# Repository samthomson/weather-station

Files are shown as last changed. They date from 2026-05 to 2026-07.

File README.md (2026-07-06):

# Nostr Weather Station

ESP8266 weather station that posts sensor data to Nostr via WebSocket with BIP-340 Schnorr signatures.

**Viewer app:** [github.com/samthomson/weather](https://github.com/samthomson/weather) — sample app for displaying weather data from Nostr events, deployed at [weather.shakespeare.wtf](https://weather.shakespeare.wtf/)

## Hardware

**Supported Boards:**
- NodeMCU v2 (ESP8266)
- ESP32 Dev Board

**Sensors:**
- DHT11 temp/humidity — also works: DHT22
- PMS5003 particulate matter — reads PM1.0, PM2.5, PM10 | also works: PMS7003
- MQ-135/MQ-7 air quality — uncalibrated gas detection 0-1023 | also works: MQ-2, other MQ series
- SSD1306 OLED display (I2C) - optional

### MVP shopping list

Wall-powered reference build for new prototypes: **ESP32**, particulates, temp/humidity/pressure, daylight, rain — **no MQ gas sensor, no OLED**.

| Qty | Part |
|-----|---|
| 1 | ESP32 dev board (same class as `board = esp32dev` in PlatformIO) |
| 1 | BME280 breakout (I2C, 3.3 V) — temperature, humidity, barometric pressure |
| 1 | PMS5003 — PM1.0, PM2.5, PM10 (include a cable if the module does not ship with one) |
| 1 | BH1750 breakout (I2C) — ambient light (lux) |
| 1 | MH-RD rain sensor module (resistive panel, analog out) |
| 1 | USB cable — connector must match the board (**Micro-USB** or **USB-C**) |
| 1 | USB wall charger — **5 V**, **≥ 1 A** (2 A is a comfortable margin for ESP32 + PMS fan) |

Hookup wire or Dupont jumpers between the dev board and breakouts are assumed by your enclosure / assembly.

**MVP firmware:** In `secrets_stationN.h`, enable `ENABLE_BME280`, `ENABLE_BH1750`, `ENABLE_RAIN`, and `ENABLE_PMS` with `PMS_MODEL "PMS5003"`; set `ENABLE_DHT`, `ENABLE_MQ`, and `ENABLE_OLED` to `false`. Use a PlatformIO ESP32 environment that pulls in the BME280 and BH1750 libraries (for example `esp32dev_station3`).

**MVP ESP32 wiring:** PMS5003 serial RX→**GPIO16**, TX→**GPIO17**. BME280 and BH1750 share **I2C** (**GPIO21**=SDA, **GPIO22**=SCL). Rain sensor analog→**GPIO34**.

Stripboard matrix + cable list: **[docs/mvp-assembly-guide.html](docs/mvp-assembly-guide.html)**. Flash & setup: below.

### MVP wire colours

Use **industry-standard** colours for power rails, and **project theme** colours on the nets with the most jumpers. One dupont colour per stripboard row; label GND / 3V3 / 5V on the board edge.

| Net | Dupont colour | Type | Jumpers |
|-----|---|---|---|
| GND | Black | standard | 5 |
| 3.3 V | Orange | theme + standard for 3V3 | 4 |
| 5 V | Red | standard | 2 |
| I²C SDA | Purple | theme | 3 |
| I²C SCL | White | theme | 3 |
| PMS TX → ESP RX | Green | other | 2 |
| ESP TX → PMS RX | Grey | theme | 2 |
| Rain AO | Blue | other | 2 |
| Rain pad → MH-RD | Blue | pad sense | 2 |

**Theme palette** (UI brand + preferred dupont stock): orange, purple, white, grey. Orange does double duty as 3.3 V (common convention). Green and blue are only used on 2-wire nets so all four theme colours land on the busier rows.

### Pin Connections

**ESP8266 (NodeMCU v2):**
- DHT11: D7
- PMS5003: TX→D5, RX→D6
- MQ sensor: A0
- OLED: I2C (D1=SCL, D2=SDA)

**ESP32:**
- DHT11: GPIO4
- PMS5003: TX→GPIO16 (RX2), RX→GPIO17 (TX2)
- MQ sensor: GPIO36 (ADC1_CH0)
- OLED: I2C (GPIO21=SDA, GPIO22=SCL)

**Note:** ESP8266 has one analog pin. ESP32 has many - great for multiple analog sensors!

## Setup

1. Install [PlatformIO](https://platformio.org/).
2. *(Optional)* For brand-new boards you do not need to edit any secrets file — the firmware ships with sensible blank defaults and a per-device captive-portal dashboard handles everything. If you want pre-baked factory defaults (handy if you flash a lot of boards), copy `include/secrets.h.example` to e.g. `include/secrets_station_mvp1.h` and fill it in.
3. Connect the board via USB and flash. For a **brand-new or recycled board**, erase first so NVS starts clean:
   ```bash
   # Erase + flash (new/recycled board — clears all NVS):
   pio run -e esp32dev_mvp3 -t erase && pio run -e esp32dev_mvp3 -t upload

   # Flash only (re-flash same board, keep NVS config):
   pio run -e esp32dev_mvp3 -t upload

   # Monitor serial output:
   pio device monitor -e esp32dev_mvp3
   ```
   Replace `mvp3` with the correct env number. All MVP envs (`esp32dev_mvp1` … `esp32dev_mvp5`) build the **same firmware**; only the first-boot defaults differ (station name `N/5`, etc.). Track which board is which in [`docs/mvp-stations.md`](docs/mvp-stations.md).

   **Do not use `esptool.py` directly** — it is not on PATH and its bundled copy has missing Python dependencies. Always use `pio run -t erase` / `pio run -t upload`.

   Default Nostr relay on first boot: `wss://relay.relaying.earth`.

   **Confirm the right board is connected** before flashing. After boot, serial prints `[wifi] AP SSID: WeatherStation-XXXXXX` every 10 s — verify `XXXXXX` matches the board's label in `docs/mvp-stations.md`.

## Configure from your phone (the dashboard)

The station permanently broadcasts its own open WiFi network for configuration. You don't need a router, an app, or an IP address.

1. Plug the station in.
2. On your phone, join the WiFi named **`WeatherStation-XXXXXX`** (`XXXXXX` is the last 6 hex of the board's MAC). It has no password.
3. The "Sign in to network" sheet pops up automatically with the dashboard. (If not, open a browser to `http://192.168.4.1`.)
4. Set your home WiFi, station name, geohash, etc. Toggle the sensors you actually have wired. Hit Save.
5. The station joins your home WiFi and starts publishing to Nostr.

You can rejoin `WeatherStation-XXXXXX` at any time to change anything — including the home WiFi password if it ever changes. Everything you change persists across power loss (stored in flash / NVS).

Once on the home network you can also reach the dashboard at `http://weather.local` (mDNS).

### What's configurable from the dashboard

- **WiFi (home)** — SSID and password, with a built-in network scan.
- **Station identity** — name, description, geohash (with a "use my GPS" button that pulls from the phone), elevation, power source, connectivity type.
- **Nostr** — relay URL (preset dropdown + custom), private key (auto-generated on first boot; reveal / copy / regenerate / paste-an-existing-one).
- **Sensors** — per-sensor on/off toggles for BME280, BH1750, MH-RD rain, PMS5003/PMS7003. Only sensors you actually have wired need to be on.
- **Advanced** — post interval, restart, factory reset.

## Events Published

### kind:16158 (replaceable) — Station Metadata

Describes the station hardware, power, and sensors:

```json
{
  "tags": [
    ["name", "Weather Station 1"],
    ["g", "w5q6u"],
    ["power", "mains"],
    ["connectivity", "wifi"],
    ["sensor", "temp", "DHT11"],
    ["sensor", "pm25", "PMS5003"]
  ]
}
```

**Power types:** Currently `mains` only. Planned: `solar`, `battery`, `solar_battery`, `usb`  
**Connectivity types:** Currently `wifi` only. Planned: `cellular`, `ethernet`, `lora`, `satellite`

### kind:4223 (regular) — Sensor Readings

Each tag: `[sensor_type, value, model]`

```json
{
  "tags": [
    ["t", "weather"],
    ["a", "16158:<pubkey>:"],
    ["temp", "22.5", "DHT11"],
    ["humidity", "65.2", "DHT11"],
    ["pm25", "12", "PMS5003"],
    ["air_quality", "627", "MQ-135"]
  ]
}
```

**Tag Structure:** Third parameter identifies sensor model for cross-station comparison and multi-sensor setups.

**Units:** temp=°C, humidity=%, pm1/pm25/pm10=µg/m³, air_quality=0-1023 (raw analog)

## Project Structure

```
├── src/main.cpp                   # Sensor reads + Nostr publish
├── src/config_store.cpp           # NVS-backed user config
├── src/web_dashboard.cpp          # Captive-portal dashboard
├── include/config_store.h
├── include/web_dashboard.h
├── include/secrets.h.example      # First-boot factory defaults template
├── include/secrets_station_mvpN.h # Per-board factory defaults
├── platformio.ini
└── README.md
```

## todo

- [ ] automated tests
- [x] web dashboard
- [ ] more modular readings
- [ ] MVP
  - [x] hardware shopping list (see **MVP shopping list** under Hardware)
  - [ ] daylight
  - [ ] rain
  - [ ] air pollution
  - [ ] temperature / humidity
  - [ ] pressure
- [ ] geohash tag for the weather station event per geohash level (https://github.com/nostr-protocol/nips/pull/2163#discussion_r2653978414)
- [ ] faulty sensor/data. omit the sensor reading in the 4223 reading, and mark the sensor as 418 in 16158
- [ ] document that its a string 9https://github.com/nostr-protocol/nips/pull/2163#discussion_r2653971649)
- [ ] nip31 alt tag (for each event?) https://github.com/nostr-protocol/nips/pull/2163#issuecomment-3693704646
- [ ] add `"observed_at": <unix timestamp in seconds>` for each 16158.
- [ ] expand past weather to general environmental data (eg soil acidity, soil moisture, etc). think of a more inclusive name. maybe terrametry (telemetry, but earth scoped)

## Air quality station

A future variant focused on indoor air quality. Goal: factory-calibrated, plug-and-trust — no per-unit calibration or burn-in. All sensors below are I²C (shared GPIO21 SDA / GPIO22 SCL), so they wire in parallel on one ESP32. MQ sensors are deliberately excluded — they need per-unit calibration and only give relative values.

- [ ] PMS5003 — PM1/2.5/10 in µg/m³ (already owned)
- [ ] SCD41 — real CO₂ (NDIR) in ppm, plus temp + humidity
- [ ] SGP41 — VOC + NOx index (relative; good for spotting change/spikes)
- [ ] BME680 (optional) — IAQ gas resistance + temp/humidity/pressure

### Possible future sensors

- [ ] Winsen ZE07-CO / ZE15-CO — carbon monoxide (electrochemical, calibrated; real safety metric). UART, not I²C.
- [ ] Sensirion SFA30 — formaldehyde (HCHO); off-gasses from furniture/flooring. I²C/UART.
- [ ] Radon detector — serious long-term indoor risk, but needs a dedicated (pricier) unit; not an I²C add-on.
- [ ] Sound level (mic) — environmental noise; beyond air quality but useful for an indoor environment station.

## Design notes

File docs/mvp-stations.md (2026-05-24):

# MVP weather stations — local registry

Track which physical ESP32 is which station. Fill in a row after each flash.

**Flash command** (same firmware for every station; env only sets first-boot factory defaults):

```bash
pio run -e esp32dev_mvp1 --target upload   # station 1
pio run -e esp32dev_mvp2 --target upload   # station 2
# … mvp3, mvp4, mvp5
```

**After flash**, read from serial boot log or join the setup WiFi:

- `device_id` — last 6 hex of MAC (also the `device_id` Nostr tag)
- Setup AP — `WeatherStation-XXXXXX` (same 6 hex suffix)
- Full MAC — printed by esptool during upload

**Reassigning a board** (e.g. old prototype #3 → production #1): flashing alone does **not** wipe dashboard config. Either use **Factory reset** on the dashboard, or update name/relay/WiFi manually.

**Default relay** (first boot only): `wss://relay.relaying.earth`

---

| # | PlatformIO env | device_id | Setup AP (SSID) | Full MAC | Flashed | Notes |
|---|---|---|---|---|---|---|
| 1 | esp32dev_mvp1 | B865E4 | WeatherStation-B865E4  | e4:65:b8:1b:43:08  | 2026-05-24 | OLD firmware (wrong MAC suffix); will become 1B4308 after reflash |
| 2 | esp32dev_mvp2 | B3A3A0 | WeatherStation-B3A3A0  | a0:a3:b3:2f:95:d8  | 2026-05-24 | OLD firmware (wrong MAC suffix); will become 2F95D8 after reflash |
| 3 | esp32dev_mvp3 | 19D3B8 | WeatherStation-19D3B8  | e4:65:b8:19:d3:b8  | 2026-05-24 | Fixed firmware flashed |
| 4 | esp32dev_mvp4 | 3141C4 | WeatherStation-3141C4  | | 2026-05-24 | |
| 5 | esp32dev_mvp5 | 0BF6BC | WeatherStation-0BF6BC  | | 2026-05-24 | |

---

## Optional (keep private)

| # | Nostr pubkey | Home WiFi SSID | Location / geohash |
|---|---|---|---|
| 1 | | | |
| 2 | | | |
| 3 | | | |
| 4 | | | |
| 5 | | | |

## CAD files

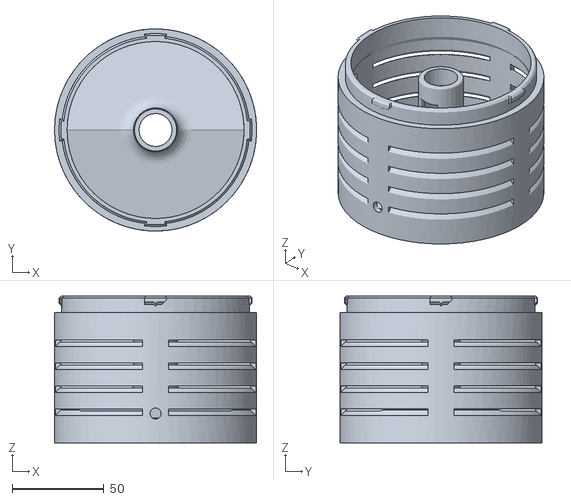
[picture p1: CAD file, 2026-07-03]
3d_files/2c_tier_louvred.stl
109.9 x 110.0 x 79.9

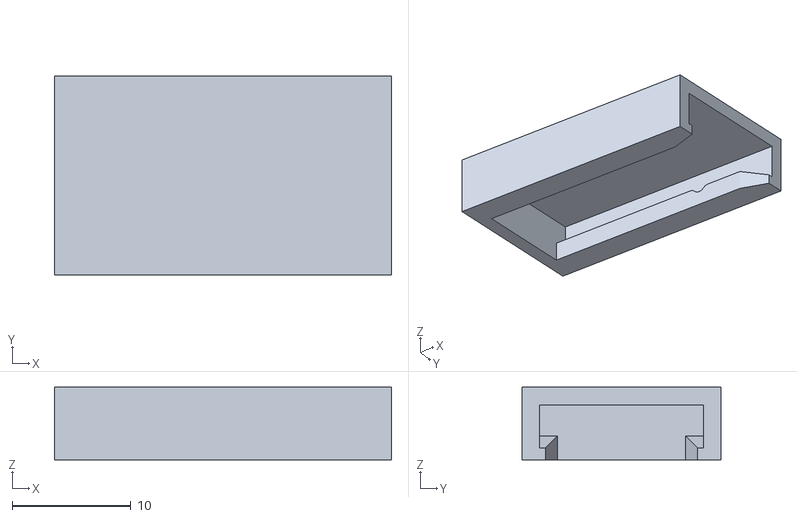
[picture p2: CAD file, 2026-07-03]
3d_files/3b2_rain_sensor_cover.stl
28.4 x 16.8 x 6.10

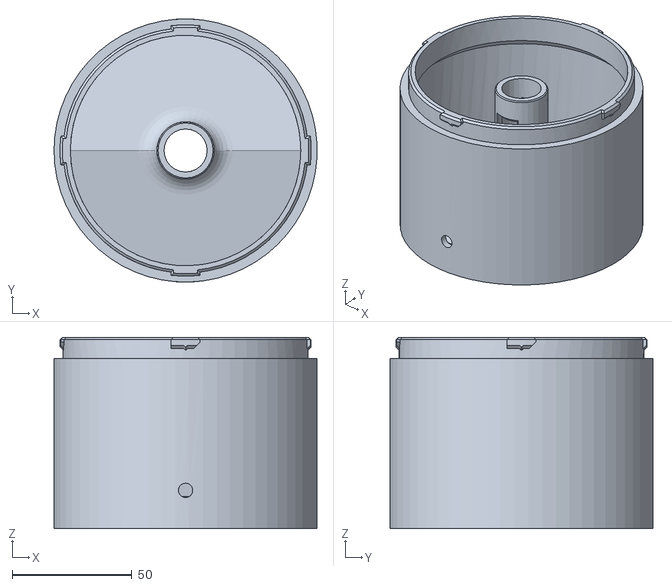
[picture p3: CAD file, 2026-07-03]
3d_files/2b_tier_solid.stl
109.9 x 110.0 x 79.9

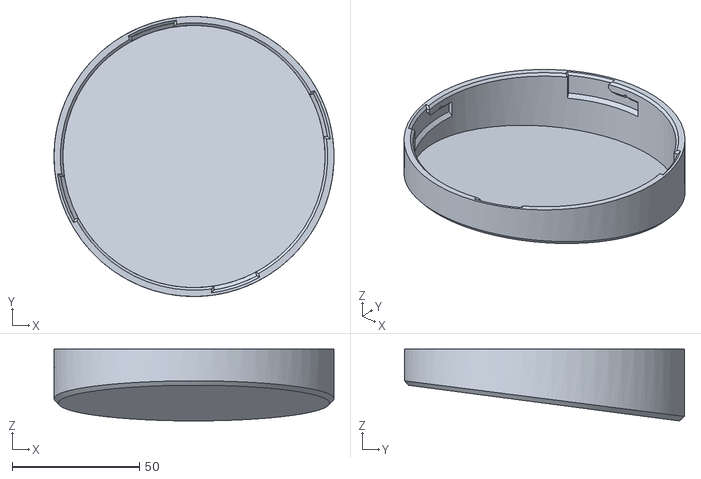
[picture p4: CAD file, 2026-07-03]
3d_files/3a_plain roof.stl
110.0 x 110.0 x 28.2

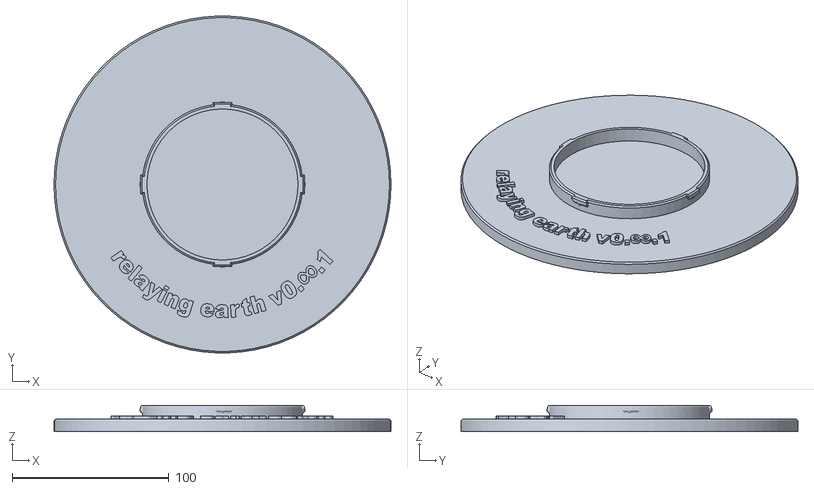
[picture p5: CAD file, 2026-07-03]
3d_files/1_base_with_text.stl
215.0 x 214.8 x 16.9

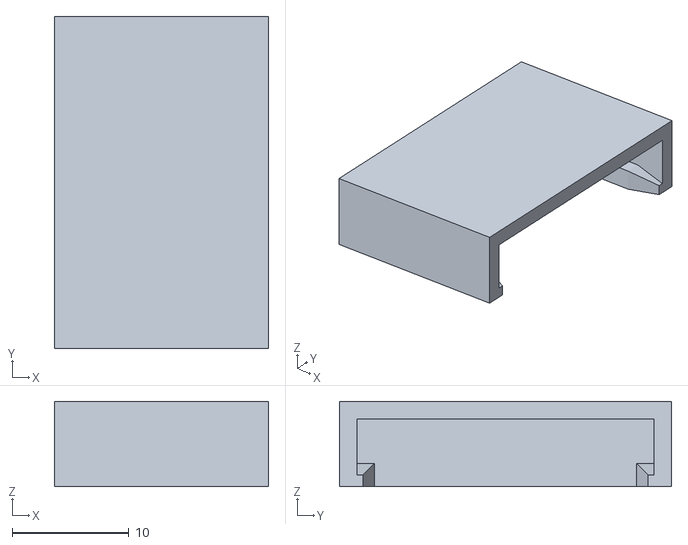
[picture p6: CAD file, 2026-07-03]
3d_files/3b3_light_sensor_cover.stl
18.4 x 28.4 x 7.30

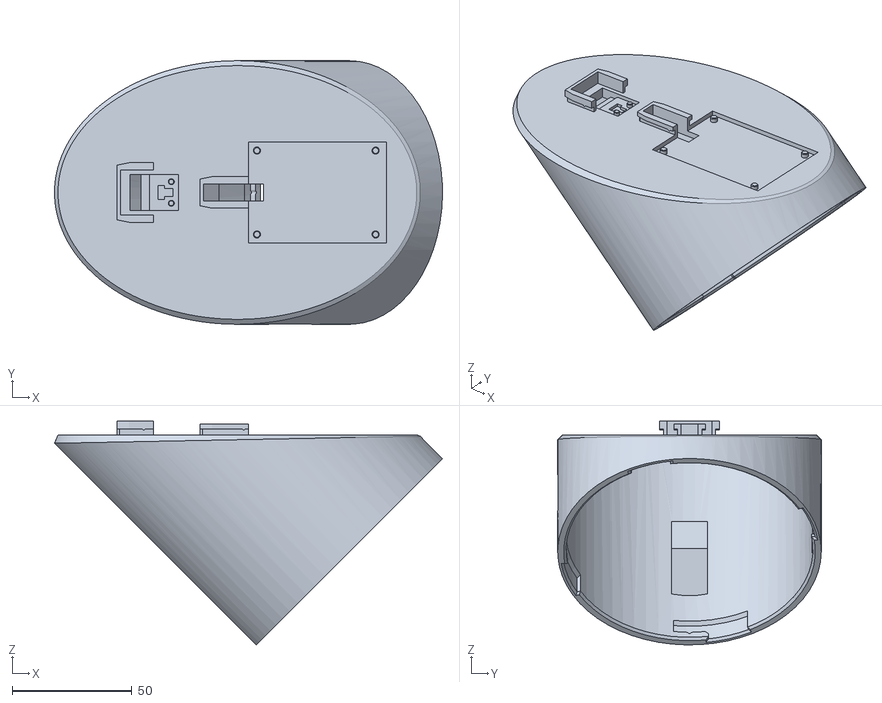
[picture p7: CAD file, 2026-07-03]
3d_files/3b_roof_with_sensors.stl
161.9 x 110.0 x 93.4

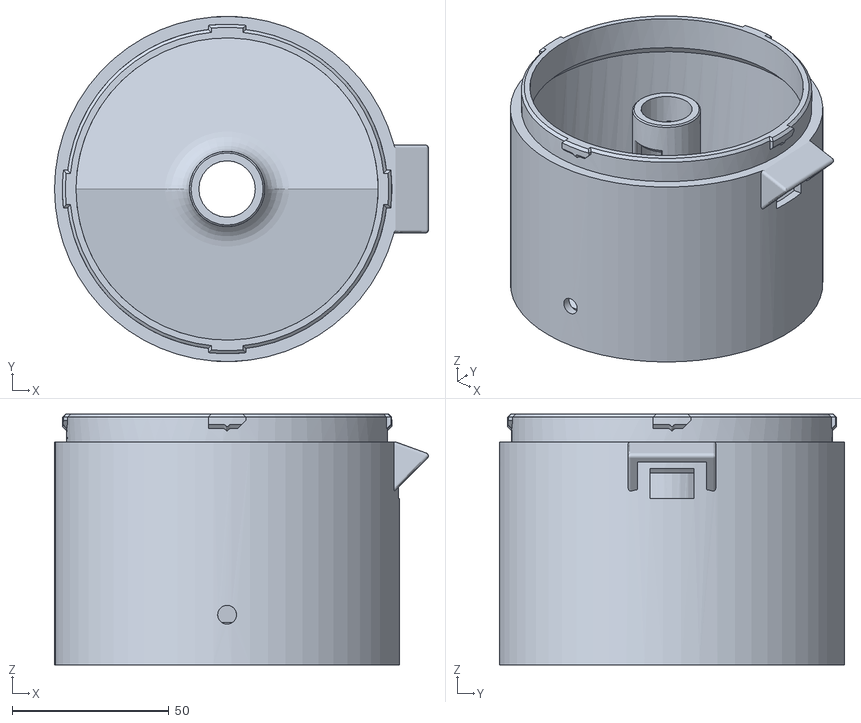
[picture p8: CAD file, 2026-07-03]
3d_files/2a_tier_esp32.stl
119.2 x 110.0 x 79.9

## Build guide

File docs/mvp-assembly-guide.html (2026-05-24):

# Weather Station — Stripboard Build

30-pin ESP32 · 6×9 cm stripboard · rows 1–8 from top

## Stripboard matrix

One row = one net. Solder each pin into any hole on that row. Male dupont leg through hole, bend on copper side. ESP32 off-board (F on ESP, M soldered).

Row | Net | ESP32 DevKitUSB at top · 30-pin | BME280I²C + 3V3 rail | BH1750I²C + 3V3 rail | PMS50035V UART | MH-RD rain3V3 + AO
1 | GND | BlackGND (left · pin 2) | BlackGND | BlackGND | BlackGND | BlackGND
2 | 3V3 | Orange3V3 | OrangeVCC | OrangeVCC | — | OrangeVCC
3 | I²C SDA | PurpleD21 | PurpleSDA | PurpleSDA | — | —
4 | I²C SCL | WhiteD22 | WhiteSCL | WhiteSCL | — | —
5 | UART PMS → ESP | GreenRX2 | — | — | GreenTXD | —
6 | UART ESP → PMS | GreyTX2 | — | — | GreyRXD | —
7 | 5V | RedVIN | — | — | RedVCC | —
8 | Rain analog | BlueD34 | — | — | — | BlueAO

## Cables

Male end soldered to perfboard on stubs. Column plugs stub ↔ tail at each tier. Wire bars are to scale (10 px wide = 1 cm).

ESP32
15 cm · F–M · perfboard stubs
Black Orange Purple White Green Grey Red Blue
BME280
15 cm · F–M · perfboard stubs
Black Orange Purple White
30 cm · M–M · column (stack connectors)
Black Orange Purple White
10 cm · F–M · sensor tails
Black Orange Purple White
BH1750
15 cm · F–M · perfboard stubs
Black Orange Purple White
30 cm · M–M · column (stack connectors)
Black Orange Purple White
10 cm · F–M · sensor tails
Black Orange Purple White
PMS5003
15 cm · F–M · perfboard stubs
Black Green Grey Red
30 cm · M–M · column (stack connectors)
Black Green Grey Red
10 cm · F–M · sensor tails
Black Green Grey Red
MH-RD board
15 cm · F–M · perfboard stubs
Black Orange Blue
30 cm · M–M · column (stack connectors)
Black Orange Blue
Rain pad → MH-RD
10 cm · F–F · component (rain pad)
Blue Blue

### Shopping list

ESP32
15 cm · F–M · perfboard stubs
Qty | Wire
1 | Black
1 | Orange
1 | Purple
1 | White
1 | Green
1 | Grey
1 | Red
1 | Blue
BME280
15 cm · F–M · perfboard stubs
Qty | Wire
1 | Black
1 | Orange
1 | Purple
1 | White
30 cm · M–M · column (stack connectors)
1 | Black
1 | Orange
1 | Purple
1 | White
10 cm · F–M · sensor tails
1 | Black
1 | Orange
1 | Purple
1 | White
BH1750
15 cm · F–M · perfboard stubs
Qty | Wire
1 | Black
1 | Orange
1 | Purple
1 | White
30 cm · M–M · column (stack connectors)
1 | Black
1 | Orange
1 | Purple
1 | White
10 cm · F–M · sensor tails
1 | Black
1 | Orange
1 | Purple
1 | White
PMS5003
15 cm · F–M · perfboard stubs
Qty | Wire
1 | Black
1 | Green
1 | Grey
1 | Red
30 cm · M–M · column (stack connectors)
1 | Black
1 | Green
1 | Grey
1 | Red
10 cm · F–M · sensor tails
1 | Black
1 | Green
1 | Grey
1 | Red
MH-RD board
15 cm · F–M · perfboard stubs
Qty | Wire
1 | Black
1 | Orange
1 | Blue
30 cm · M–M · column (stack connectors)
1 | Black
1 | Orange
1 | Blue
Rain pad → MH-RD
10 cm · F–F · component (rain pad)
Qty | Wire
2 | Blue
52 wires total

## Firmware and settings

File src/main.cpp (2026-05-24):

#include <Arduino.h>
#include <math.h>

// Include station-specific secrets FIRST (defines sensor flags)
#ifndef SECRETS_FILE
  #error "SECRETS_FILE must be defined! Use -DSECRETS_FILE=\"secrets_stationX.h\" in platformio.ini"
#endif
#include SECRETS_FILE

// Board-specific includes
#ifdef ESP32
  #include <WiFi.h>
  #include <WiFiClientSecure.h>
  #include "soc/soc.h"
  #include "soc/rtc_cntl_reg.h"
#else
  #include <ESP8266WiFi.h>
  #include <WiFiClientSecure.h>
  #include <SoftwareSerial.h>
#endif

#include <time.h>
#include <ArduinoJson.h>
#if ENABLE_DHT
  #include "DHT.h"
#endif
#include <Wire.h>
#if ENABLE_BME280
  #include <Adafruit_BME280.h>
  #include <Adafruit_BMP280.h>
#endif
#if ENABLE_BH1750
  #include <BH1750.h>
#endif
#if ENABLE_SPS30
  #include <SensirionI2cSps30.h>
#endif
#if ENABLE_SDS011
  #include <SdsDustSensor.h>
#endif
#include <Adafruit_GFX.h>
#include <Adafruit_SSD1306.h>
#include <WebSocketsClient.h>

#include "config_store.h"
#include "web_dashboard.h"

#ifdef ESP32
  #include <mbedtls/sha256.h>
  #include "uECC.h"
#else
  #include <bearssl/bearssl_hash.h>
  #include "uECC.h"
#endif

// secp256k1 curve order n
static const uint8_t SECP256K1_ORDER[32] = {
  0xFF, 0xFF, 0xFF, 0xFF, 0xFF, 0xFF, 0xFF, 0xFF,
  0xFF, 0xFF, 0xFF, 0xFF, 0xFF, 0xFF, 0xFF, 0xFE,
  0xBA, 0xAE, 0xDC, 0xE6, 0xAF, 0x48, 0xA0, 0x3B,
  0xBF, 0xD2, 0x5E, 0x8C, 0xD0, 0x36, 0x41, 0x41
};

// Pre-computed tag hashes for BIP-340
static const uint8_t TAG_CHALLENGE[32] = {
  0x7b, 0xb5, 0x2d, 0x7a, 0x9f, 0xef, 0x58, 0x32,
  0x3e, 0xb1, 0xbf, 0x7a, 0x40, 0x7d, 0xb3, 0x82,
  0xd2, 0xf3, 0xf2, 0xd8, 0x1b, 0xb1, 0x22, 0x4f,
  0x49, 0xfe, 0x51, 0x8f, 0x6d, 0x48, 0xd3, 0x7c
};
static const uint8_t TAG_NONCE[32] = {
  0x07, 0x49, 0x77, 0x34, 0xa7, 0x9b, 0xcb, 0x35,
  0x5b, 0x9b, 0x8c, 0x7d, 0x03, 0x4f, 0x12, 0x1c,
  0xf4, 0x34, 0xd7, 0x3a, 0xf6, 0x39, 0x7b, 0x96,
  0xb8, 0x0a, 0xab, 0x80, 0x51, 0x85, 0x45, 0x69
};
static const uint8_t TAG_AUX[32] = {
  0xf1, 0xef, 0x4e, 0x5e, 0xc0, 0x63, 0xca, 0xda,
  0xf7, 0xef, 0xf4, 0xb9, 0x8e, 0x3b, 0x67, 0xc8,
  0xa7, 0x90, 0xae, 0xfe, 0x0f, 0x05, 0xfc, 0x7a,
  0x5f, 0x21, 0xa9, 0x93, 0x01, 0x6c, 0x3a, 0xba
};

// All user-settable values come from config_store::current(); the compile-time
// #defines in SECRETS_FILE are only consulted on first boot to seed NVS.
// Default values for things that aren't user-settable from the dashboard yet:
const uint16_t NOSTR_DEFAULT_TLS_PORT = 443;
const uint16_t NOSTR_DEFAULT_WS_PORT  = 80;

// Parsed relay URL kept in sync with config_store::current().nostr_relay.
struct RelayURL { String host; uint16_t port; String path; bool ssl; };
static RelayURL currentRelay;

// Nostr tag names (standardized)
const char* TAG_TEMP = "temp";
const char* TAG_HUMIDITY = "humidity";
const char* TAG_PM1 = "pm1";
const char* TAG_PM25 = "pm25";
const char* TAG_PM10 = "pm10";
const char* TAG_AIR_QUALITY = "air_quality";
const char* TAG_HASHTAG = "t";
const char* HASHTAG_WEATHER = "weather";

// Sensor models
const char* MODEL_DHT11 = "DHT11";
const char* MODEL_BME280 = "BME280";
const char* MODEL_BMP280 = "BMP280";
const char* MODEL_PMS5003 = "PMS5003";
const char* MODEL_PMS7003 = "PMS7003";
const char* MODEL_SPS30 = "SPS30";
const char* MODEL_SDS011 = "SDS011";
const char* MODEL_MQ135 = "MQ-135";
const char* MODEL_BH1750 = "BH1750";
const char* MODEL_MHRD = "MH-RD";

// Nostr tag names for additional sensors
const char* TAG_PRESSURE = "pressure";
const char* TAG_LIGHT = "light";
const char* TAG_RAIN = "rain";

// Sensor types available on this station (for metadata)
struct SensorInfo {
  const char* type;
  const char* model;
};

// Build sensor list modularly - each enabled sensor adds its readings
// Validate that required models are defined if sensors are enabled
#if ENABLE_PMS && !defined(PMS_MODEL)
  #error "PMS_MODEL must be defined in secrets file when ENABLE_PMS is true"
#endif

const SensorInfo sensors[] = {
  #if ENABLE_DHT
    {TAG_TEMP, MODEL_DHT11},
    {TAG_HUMIDITY, MODEL_DHT11},
  #endif
  #if ENABLE_BME280
    {TAG_TEMP, MODEL_BME280},
    {TAG_HUMIDITY, MODEL_BME280},  // Only for BME280, not BMP280
    {TAG_PRESSURE, MODEL_BME280},
  #endif
  #if ENABLE_BMP280
    {TAG_TEMP, MODEL_BMP280},
    {TAG_PRESSURE, MODEL_BMP280},
  #endif
  #if ENABLE_PMS
    {TAG_PM1, PMS_MODEL},
    {TAG_PM25, PMS_MODEL},
    {TAG_PM10, PMS_MODEL},
  #endif
  #if ENABLE_SPS30
    {TAG_PM1, MODEL_SPS30},
    {TAG_PM25, MODEL_SPS30},
    {TAG_PM10, MODEL_SPS30},
  #endif
  #if ENABLE_SDS011
    {TAG_PM25, MODEL_SDS011},
    {TAG_PM10, MODEL_SDS011},
  #endif
  #if ENABLE_MQ
    {TAG_AIR_QUALITY, MODEL_MQ135},
  #endif
};

const int sensorCount = sizeof(sensors) / sizeof(sensors[0]);

// PM sensor serial port - board-specific (PMS5003/PMS7003 and SDS011)
#ifdef ESP32
  HardwareSerial pmsSerial(2);  // ESP32 UART2
  #define PMS_SERIAL pmsSerial
#else
  SoftwareSerial mySerial(D5, D6);  // ESP8266
  #define PMS_SERIAL mySerial
#endif

unsigned int pm1 = 0, pm2_5 = 0, pm10 = 0;
bool pmDataReceived = false;  // set on first valid PM frame; omit PM reading tags until then (NIP)

#if ENABLE_SPS30
  SensirionI2cSps30 sps30;
  bool sps30DataReceived = false;
#endif
#if ENABLE_SDS011
  SdsDustSensor sds011(PMS_SERIAL);  // Uses same UART2 on ESP32 (RX=16, TX=17)
  bool sds011DataReceived = false;
#endif

// DHT sensor pin - board-specific
#if ENABLE_DHT
  #define DHTTYPE DHT11
  #ifdef ESP32
    #define DHT_PIN 4  // GPIO4 on ESP32
  #else
    #define DHT_PIN D7  // D7 on ESP8266
  #endif
  DHT dht(DHT_PIN, DHTTYPE);
#endif

// BME280/BMP280 sensor (I2C)
#if ENABLE_BME280
  Adafruit_BME280 bme;
  Adafruit_BMP280 bmp;
  bool bmeAvailable = false;
  bool bmpAvailable = false;  // BMP280 = no humidity, just temp+pressure
  bool bmeHasReading = false;
  bool bmpHasReading = false;
#endif

// BH1750 light sensor (I2C)
#if ENABLE_BH1750
  BH1750 lightMeter;
  bool bh1750Available = false;
#endif

// Rain sensor pin - board-specific
#ifdef ESP32
  #define RAIN_PIN 34  // GPIO34 (ADC1_CH6) on ESP32
#else
  #define RAIN_PIN A0  // A0 on ESP8266 (shared with MQ if both enabled)
#endif

float t = 0, h = 0, p = 0;  // temperature, humidity, pressure
float lux = NAN;            // BH1750 lux; NAN until first valid read
unsigned int rainValue = 0; // rain sensor (0-4095 on ESP32, 0-1023 on ESP8266)

// MQ sensor analog pin - board-specific
#ifdef ESP32
  #define MQ_PIN 36  // GPIO36 (ADC1_CH0) on ESP32
#else
  #define MQ_PIN A0  // A0 on ESP8266
#endif
unsigned int airQuality = 0;
#define SCREEN_WIDTH 128
#define SCREEN_HEIGHT 64
Adafruit_SSD1306 display(SCREEN_WIDTH, SCREEN_HEIGHT, &Wire, -1);
WebSocketsClient webSocket;
bool wsConnected = false;
bool displayAvailable = false;
String nostrPubkey = "";
uint8_t privKeyBytes[32];
uint8_t pubKeyBytes[32];
// millis() of last successful publish; surfaced on the dashboard.
unsigned long lastPublishMs = 0;

// Forward declarations
void connectWiFi();
void setupNostrRelay();
static RelayURL parseRelayUrl(const String& url);
static void applyConfigChanges(bool wifiChanged, bool relayChanged, bool keyChanged, bool sensorsChanged, bool intervalChanged);
static void publishDashboardStatus();
static void initRuntimeSensors();
static WxConfig buildFactoryDefaults();
// 6-char uppercase hex suffix of the eFuse MAC. Stable per physical board,
// burned at factory, identical to the AP SSID suffix.
static String getDeviceId();
void webSocketEvent(WStype_t type, uint8_t* payload, size_t length);
void pmReadData();
#if ENABLE_SPS30
void sps30ReadData();
#endif
#if ENABLE_SDS011
void sds011ReadData();
#endif
void dhtData();
#if ENABLE_BME280
void bmeData();
#endif
#if ENABLE_BH1750
void lightData();
#endif
#if ENABLE_RAIN
void rainData();
// GPIO34 has no internal pull, so a "not connected" pin reads random noise
// across the full ADC range. We treat the sensor as present only after we've
// seen several consecutive stable, high (dry) readings -- a signature a
// floating pin never holds. Once latched, every subsequent reading is treated
// as real weather data regardless of value.
static unsigned rainSpread = 999;
static unsigned rainSampleCount = 0;
static unsigned rainDryStreak = 0;
static bool rainEverConnected = false;

static bool rainValid() { return rainEverConnected; }

static void rainUpdateConnectedLatch(unsigned avg, unsigned spread) {
  if (rainEverConnected) return;
  if (spread <= 80 && avg >= 1800) rainDryStreak++;
  else rainDryStreak = 0;
  if (rainDryStreak >= 5) rainEverConnected = true;
}
#endif
void mqReadData();
void displayOled();
void derivePubkey();
String bytesToHex(uint8_t* bytes, int len);
void hexToBytes(const char* hex, uint8_t* bytes, int len);
void sha256Raw(const uint8_t* data, size_t len, uint8_t* out);
void taggedHash(const uint8_t* tag, const uint8_t* data, size_t len, uint8_t* out);
bool schnorrSign(const uint8_t* privkey, const uint8_t* msg, uint8_t* sig);
String createAndSignNostrEvent(float temp, float humidity, unsigned int pm1_val, unsigned int pm25_val, unsigned int pm10_val, unsigned int aq_val);
String createMetadataEvent();
void sendMetadataEvent();

// --- Tag builders (Nostr reading + metadata tags) ---
static void appendReadingTag(String& dest, const char* type, const char* model, float value) {
  dest += ",[\""; dest += type; dest += "\",\""; dest += String(value, 1); dest += "\",\""; dest += model; dest += "\"]";
}
static void appendReadingTag(String& dest, const char* type, const char* model, unsigned int value) {
  dest += ",[\""; dest += type; dest += "\",\""; dest += String(value); dest += "\",\""; dest += model; dest += "\"]";
}
static void appendSensorTag(String& dest, const char* type, const char* model) {
  dest += ",[\"sensor\",\""; dest += type; dest += "\",\""; dest += model; dest += "\"]";
}
static void appendSensorStatusTag(String& dest, const char* type, const char* model, bool ok) {
  dest += ",[\"sensor_status\",\""; dest += type; dest += "\",\""; dest += model; dest += "\",\""; dest += (ok ? "ok" : "418"); dest += "\"]";
}
// One (type, model) → always add sensor tag + sensor_status(ok). Use for DHT, BH1750, Rain, PMS, MQ.
static void appendSensorAndStatus(String& dest, const char* type, const char* model, bool ok) {
  appendSensorTag(dest, type, model);
  appendSensorStatusTag(dest, type, model, ok);
}

// --- Per-sensor validation (NIP: omit reading / status 418 when invalid) ---
// Each sensor type has one validator. Rain/MQ have no fault detection, so we always pass true for them.
#if ENABLE_DHT
static bool dhtValid() { return !isnan(t) && !isnan(h); }
#endif
#if ENABLE_BME280
static bool enviroReadingOkForNostr() { return (bmeAvailable && bmeHasReading) || (bmpAvailable && bmpHasReading); }

// BME280 sensor range (datasheet); values outside are almost always corrupt I2C frames.
static bool bmeEnviroPlausible(float tempC, float humPct, float pressHpa) {
  if (isnan((double)tempC) || isnan((double)humPct) || isnan((double)pressHpa)) return false;
  if (tempC < -40.0f || tempC > 85.0f) return false;
  if (humPct < 0.0f || humPct > 100.0f) return false;
  if (pressHpa < 260.0f || pressHpa > 1100.0f) return false;
  return true;
}
#endif
#if ENABLE_PMS
static bool pmsValid() { return pmDataReceived; }  // set on first valid frame; omit PM tags until then (NIP)
#endif
#if ENABLE_SPS30
static bool sps30Valid() { return sps30DataReceived; }
#endif
#if ENABLE_SDS011
static bool sds011Valid() { return sds011DataReceived; }
#endif
#if ENABLE_BH1750
// claws/BH1750 returns negative values on I2C read failure — do not relay as lux.
static bool bh1750Valid() {
  return bh1750Available && !isnan((double)lux) && lux >= 0.0f;
}
#endif

// BME280 (temp+humidity+pressure) vs BMP280 (temp+pressure only) — one helper, two model names
#if ENABLE_BME280
static void appendPressureSensorReadingTags(String& dest, const char* model, bool includeHumidity) {
  appendReadingTag(dest, TAG_TEMP, model, t);
  if (includeHumidity) appendReadingTag(dest, TAG_HUMIDITY, model, h);
  appendReadingTag(dest, TAG_PRESSURE, model, p);
}
static void appendPressureSensorMetadataTags(String& dest, const char* model, bool includeHumidity, bool ok) {
  if (ok) {
    appendSensorTag(dest, TAG_TEMP, model);
    if (includeHumidity) appendSensorTag(dest, TAG_HUMIDITY, model);
    appendSensorTag(dest, TAG_PRESSURE, model);
  }
  appendSensorStatusTag(dest, TAG_TEMP, model, ok);
  if (includeHumidity) appendSensorStatusTag(dest, TAG_HUMIDITY, model, ok);
  appendSensorStatusTag(dest, TAG_PRESSURE, model, ok);
}
#endif
#if ENABLE_DHT
static void appendDhtReadingTags(String& dest) {
  if (!dhtValid()) return;
  appendReadingTag(dest, TAG_TEMP, MODEL_DHT11, t);
  appendReadingTag(dest, TAG_HUMIDITY, MODEL_DHT11, h);
}
#endif
// Shared helper: append pm1, pm25, pm10 with given model (used by PMS and SPS30)
static void appendPmReadingTagsWithModel(String& dest, const char* model, unsigned int v1, unsigned int v25, unsigned int v10) {
  appendReadingTag(dest, TAG_PM1, model, v1);
  appendReadingTag(dest, TAG_PM25, model, v25);
  appendReadingTag(dest, TAG_PM10, model, v10);
}
#if ENABLE_PMS
static void appendPmReadingTags(String& dest) {
  if (!pmsValid()) return;
  appendPmReadingTagsWithModel(dest, PMS_MODEL, pm1, pm2_5, pm10);
}
#endif
#if ENABLE_SPS30
static void appendSps30ReadingTags(String& dest) {
  if (!sps30Valid()) return;
  appendPmReadingTagsWithModel(dest, MODEL_SPS30, pm1, pm2_5, pm10);
}
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
void loop() {
  // Always service the dashboard + DNS captive portal first so the UI stays
  // responsive even when STA / WebSocket are flapping.
  web_dashboard::handle();
  webSocket.loop();

  WxConfig& cfg = config_store::current();

  // Best-effort background STA reconnect if user has WiFi creds but we are
  // currently disconnected (e.g. credentials were just changed).
  static unsigned long lastStaRetry = 0;
  if (cfg.wifi_ssid.length() > 0 && WiFi.status() != WL_CONNECTED && millis() - lastStaRetry > 15000) {
    Serial.println("[wifi] reconnect attempt");
    WiFi.begin(cfg.wifi_ssid.c_str(), cfg.wifi_pass.c_str());
    lastStaRetry = millis();
  }

  static unsigned long lastSensor = 0, lastPost = 0, lastStatus = 0, lastWifiLog = 0;
  unsigned long now = millis();

  if (now - lastWifiLog > 10000) {
    lastWifiLog = now;
    Serial.printf("[wifi] AP SSID: %s  AP IP: %s  STA: %s\n",
      web_dashboard::apSsid().c_str(),
      web_dashboard::apIp().c_str(),
      WiFi.status() == WL_CONNECTED ? WiFi.localIP().toString().c_str() : "disconnected");
  }

  if (now - lastSensor > 2000) {
    #if ENABLE_PMS
      if (cfg.en_pms) pmReadData();
    #endif
    #if ENABLE_SPS30
      sps30ReadData();
    #endif
    #if ENABLE_SDS011
      sds011ReadData();
    #endif
    #if ENABLE_DHT
      dhtData();
    #endif
    #if ENABLE_BME280
      if (cfg.en_bme280) bmeData();
    #endif
    #if ENABLE_BH1750
      if (cfg.en_bh1750) lightData();
    #endif
    #if ENABLE_RAIN
      if (cfg.en_rain) rainData();
    #endif
    #if ENABLE_MQ
      mqReadData();
    #endif
    #if ENABLE_OLED
      displayOled();
    #endif
    lastSensor = now;
  }

  if (now - lastStatus > 1000) {
    publishDashboardStatus();
    lastStatus = now;
  }

  uint32_t postIntervalMs = cfg.post_interval_ms > 10000 ? cfg.post_interval_ms : 60000;
  if (now - lastPost > postIntervalMs) {
    // Do we have any valid reading to publish? Each validator already returns
    // false when the sensor is runtime-disabled (because nothing wrote to the
    // backing globals), so we don't re-check cfg.en_* here.
    bool hasData = false;
    #if ENABLE_DHT
      hasData = hasData || (t > 0);
    #endif
    #if ENABLE_BME280
      hasData = hasData || enviroReadingOkForNostr();
    #endif
    #if ENABLE_BH1750
      hasData = hasData || bh1750Valid();
    #endif
    #if ENABLE_RAIN
      hasData = hasData || rainValid();
    #endif
    #if ENABLE_PMS
      hasData = hasData || (pm2_5 > 0);
    #endif
    #if ENABLE_SPS30
      hasData = hasData || sps30DataReceived;
    #endif
    #if ENABLE_SDS011
      hasData = hasData || sds011DataReceived;
    #endif

    if (wsConnected && (hasData || !ENABLE_DHT)) {
      String event = createAndSignNostrEvent(t, h, pm1, pm2_5, pm10, airQuality);
      if (event.length() > 0) {
        Serial.println("Sending reading event...");
        String msg = "[\"EVENT\"," + event + "]";
        webSocket.sendTXT(msg);
        lastPublishMs = millis();
      }
      sendMetadataEvent();
    }
    lastPost = now;
  }
  delay(2);
}

void connectWiFi() {
  WxConfig& cfg = config_store::current();
  if (cfg.wifi_ssid.length() == 0) {
    Serial.println("[wifi] No SSID set; staying in AP-only mode for now");
    return;
  }
  // AP mode is already running (see web_dashboard::begin); WIFI_AP_STA was set
  // there. Just start the STA connection.
  WiFi.begin(cfg.wifi_ssid.c_str(), cfg.wifi_pass.c_str());
  Serial.print("WiFi");
  unsigned long start = millis();
  while (WiFi.status() != WL_CONNECTED && millis() - start < 15000) {
    delay(500);
    Serial.print(".");
  }
  if (WiFi.status() == WL_CONNECTED) {
    Serial.print(" OK ");
    Serial.println(WiFi.localIP());
  } else {
    Serial.println(" timeout (continuing; STA will retry in background)");
  }
}

static RelayURL parseRelayUrl(const String& url) {
  RelayURL r{ "", NOSTR_DEFAULT_TLS_PORT, "/", true };
  if (url.length() == 0) return r;
  String u = url;
  if (u.startsWith("wss://"))      { r.ssl = true;  r.port = NOSTR_DEFAULT_TLS_PORT; u = u.substring(6); }
  else if (u.startsWith("ws://"))  { r.ssl = false; r.port = NOSTR_DEFAULT_WS_PORT;  u = u.substring(5); }
  // bare "host[:port][/path]" defaults to wss://
  int slash = u.indexOf('/');
  String hostport = slash >= 0 ? u.substring(0, slash) : u;
  r.path = slash >= 0 ? u.substring(slash) : "/";
  int colon = hostport.indexOf(':');
  if (colon >= 0) {
    r.host = hostport.substring(0, colon);
    r.port = (uint16_t)hostport.substring(colon + 1).toInt();
  } else {
    r.host = hostport;
  }
  return r;
}

void setupNostrRelay() {
  WxConfig& cfg = config_store::current();
  currentRelay = parseRelayUrl(cfg.nostr_relay);
  if (currentRelay.host.length() == 0) {
    Serial.println("[nostr] No relay configured; skipping connect");
    return;
  }
  Serial.print("[nostr] Connecting to ");
  Serial.print(currentRelay.ssl ? "wss://" : "ws://");
  Serial.print(currentRelay.host);
  Serial.print(":"); Serial.print(currentRelay.port);
  Serial.println(currentRelay.path);
  if (currentRelay.ssl) webSocket.beginSSL(currentRelay.host.c_str(), currentRelay.port, currentRelay.path.c_str());
  else                  webSocket.begin(currentRelay.host.c_str(), currentRelay.port, currentRelay.path.c_str());
  webSocket.onEvent(webSocketEvent);
  webSocket.setReconnectInterval(5000);
  webSocket.enableHeartbeat(15000, 3000, 2);
}

void webSocketEvent(WStype_t type, uint8_t* payload, size_t length) {
  switch(type) {
    case WStype_DISCONNECTED: wsConnected = false; Serial.println("[WS] Disconnected"); break;
    case WStype_CONNECTED: wsConnected = true; Serial.println("[WS] Connected"); break;
    case WStype_TEXT: Serial.print("[WS] "); Serial.println((char*)payload); break;
    default: break;
  }
}

void pmReadData() {
  int index = 0;
  char value, prev = 0;
  while (PMS_SERIAL.available()) {
    value = PMS_SERIAL.read();
    if ((index == 0 && value != 0x42) || (index == 1 && value != 0x4d)) break;
    if (index == 4 || index == 6 || index == 8) prev = value;
    else if (index == 5) pm1 = 256 * prev + value;
    else if (index == 7) pm2_5 = 256 * prev + value;
    else if (index == 9) {
      pm10 = 256 * prev + value;
      pmDataReceived = true;  // valid frame received
    }
    else if (index > 15) break;
    index++;
  }
  while(PMS_SERIAL.available()) PMS_SERIAL.read();
}

#if ENABLE_SPS30
void sps30ReadData() {
  uint16_t mc1p0, mc2p5, mc10p0;
  uint16_t nc0p5, nc1p0, nc2p5, nc4p0, nc10p0;
  uint16_t typical;
  int16_t err = sps30.readMeasurementData(mc1p0, mc2p5, mc10p0, nc0p5, nc1p0, nc2p5, nc4p0, nc10p0, typical);
  if (err == 0) {
    pm1 = (unsigned int)mc1p0;
    pm2_5 = (unsigned int)mc2p5;
    pm10 = (unsigned int)mc10p0;
    sps30DataReceived = true;
    Serial.print("SPS30 PM1:"); Serial.print(pm1); Serial.print(" PM2.5:"); Serial.print(pm2_5); Serial.print(" PM10:"); Serial.println(pm10);
  }
}
#endif

#if ENABLE_SDS011
void sds011ReadData() {
  PmResult res = sds011.readPm();
  if (res.isOk()) {
    pm1 = 0;  // SDS011 does not report PM1
    pm2_5 = (unsigned int)(res.pm25 + 0.5f);
    pm10 = (unsigned int)(res.pm10 + 0.5f);
    sds011DataReceived = true;
    Serial.print("SDS011 PM2.5:"); Serial.print(pm2_5); Serial.print(" PM10:"); Serial.println(pm10);
  }
}
#endif

#if ENABLE_DHT
void dhtData() {
  h = dht.readHumidity();
  t = dht.readTemperature();
  if (!isnan(t)) {
    Serial.print("T:"); Serial.print(t,1); Serial.print(" H:"); Serial.println(h,1);
  }
}
#endif

#if ENABLE_BME280
void bmeData() {
  if (bmeAvailable) {
    float nt = bme.readTemperature();
    float nh = bme.readHumidity();
    float np = bme.readPressure() / 100.0F;
    if (bmeEnviroPlausible(nt, nh, np)) {
      t = nt;
      h = nh;
      p = np;
      bmeHasReading = true;
      Serial.print("BME280 - T:");
      Serial.print(t, 1);
      Serial.print(" H:");
      Serial.print(h, 1);
      Serial.print(" P:");
      Serial.print(p, 1);
      Serial.println("hPa");
    }
  } else if (bmpAvailable) {
    float nt = bmp.readTemperature();
    float np = bmp.readPressure() / 100.0F;
    if (!isnan((double)nt) && !isnan((double)np) && nt >= -40.0f && nt <= 85.0f && np > 260.0f && np < 1100.0f) {
      t = nt;
      h = 0;
      p = np;
      bmpHasReading = true;
      Serial.print("BMP280 - T:");
      Serial.print(t, 1);
      Serial.print(" P:");
      Serial.print(p, 1);
      Serial.println("hPa");
    }
  }
}
#endif
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

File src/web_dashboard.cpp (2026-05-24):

#include "web_dashboard.h"

#include "config_store.h"

#include <WiFi.h>
#include <WebServer.h>
#include <DNSServer.h>
#include <ESPmDNS.h>
#include <ArduinoJson.h>

namespace {
  WebServer server(80);
  DNSServer dns;
  const byte DNS_PORT = 53;
  IPAddress AP_IP(192, 168, 4, 1);
  IPAddress AP_NETMASK(255, 255, 255, 0);

  DashboardCallbacks cb;
  DashboardStatus status;
  String g_ap_ssid;

  String macSuffix() {
    // getEfuseMac() packs mac[0..5] into a uint64 little-endian, so
    // mac[3..5] (the unique device bytes) sit at bit offsets 24, 32, 40.
    // mac[0..2] is the shared OUI prefix and must NOT be used here.
    uint64_t chipId = ESP.getEfuseMac();
    char buf[7];
    snprintf(buf, sizeof(buf), "%02X%02X%02X",
             (unsigned)((chipId >> 24) & 0xFF),
             (unsigned)((chipId >> 32) & 0xFF),
             (unsigned)((chipId >> 40) & 0xFF));
    return String(buf);
  }

  // --- Embedded dashboard page ---
  const char DASHBOARD_HTML[] PROGMEM = R"HTML(<!DOCTYPE html>
<html lang="en">
<head>
<meta charset="utf-8">
<meta name="viewport" content="width=device-width,initial-scale=1">
<title>Weather Station</title>
<style>
:root{
  --ink:#2a2521;--bg:#fbf7f0;--surface:#ffffff;--surface-hi:#f4ede0;
  --border:#e2dac8;--border-hi:#c8bca5;
  --text:#2a2521;--text-muted:#766c5f;--text-dim:#9a8f80;
  --orange:#d97e2e;--orange-hi:#c66c1f;--orange-soft:#fbe9d2;
  --purple:#7c5fb8;--purple-hi:#6a4ca8;--purple-soft:#ece5f6;
  --err:#c0392b;--err-soft:#fbe5e0;
}
*{box-sizing:border-box}
html,body{background:var(--bg)}
body{font-family:-apple-system,'Inter','Segoe UI',system-ui,sans-serif;margin:0 auto;padding:0 16px 32px;max-width:640px;background:var(--bg);color:var(--text);line-height:1.45}
header.brand{margin:0 -16px 8px;padding:0}
.brand-bar{height:4px;background:linear-gradient(90deg,var(--orange) 0%,var(--orange) 50%,var(--purple) 100%)}
header.brand .brand-inner{padding:18px 16px 8px}
h1{margin:0;font-size:22px;font-weight:700;letter-spacing:-.01em;color:var(--orange)}
h1 .dot{display:inline-block;width:8px;height:8px;border-radius:50%;background:var(--purple);margin:0 8px 2px 0;vertical-align:middle}
h2{margin:28px 0 10px;font-size:13px;font-weight:700;text-transform:uppercase;letter-spacing:.08em;color:var(--purple);border-bottom:1px solid var(--border);padding-bottom:6px}
label{display:block;margin:10px 0 4px;font-size:13px;color:var(--text-muted);font-weight:500}
input,select,button,textarea{width:100%;padding:11px 12px;font-size:16px;background:var(--surface);color:var(--text);border:1px solid var(--border);border-radius:8px;font-family:inherit;transition:border-color .15s,box-shadow .15s,background .15s}
input:focus,select:focus,textarea:focus{outline:none;border-color:var(--orange);box-shadow:0 0 0 3px var(--orange-soft)}
input[readonly]{background:var(--surface-hi);color:var(--text-muted)}
button{background:var(--orange);color:#fff;border:none;font-weight:700;margin-top:10px;cursor:pointer;letter-spacing:.01em;box-shadow:0 1px 2px rgba(0,0,0,.06)}
button:hover{background:var(--orange-hi)}
button:active{transform:translateY(1px);box-shadow:none}
button.warn{background:var(--err);color:#fff}
button.secondary{background:var(--surface);color:var(--text);border:1px solid var(--border);box-shadow:0 1px 2px rgba(0,0,0,.04)}
button.secondary:hover{background:var(--surface-hi);border-color:var(--border-hi)}
.row{display:flex;gap:8px;align-items:flex-end}
.row>*{flex:1}
.row>button{flex:0 0 auto;width:auto;padding-left:16px;padding-right:16px}
.pill{display:inline-block;padding:3px 10px;border-radius:999px;background:var(--surface-hi);color:var(--text);font-size:12px;font-weight:600;margin-right:4px;border:1px solid var(--border)}
.pill.ok{background:var(--purple-soft);color:var(--purple-hi);border-color:var(--purple)}
.pill.warn{background:var(--orange-soft);color:var(--orange-hi);border-color:var(--orange)}
.pill.err{background:var(--err-soft);color:var(--err);border-color:var(--err)}
.muted{color:var(--text-muted);font-size:12px}
.wifilist{display:flex;flex-direction:column;gap:4px;max-height:220px;overflow-y:auto;margin:8px 0;padding:6px;background:var(--surface-hi);border:1px solid var(--border);border-radius:8px}
.wifilist .ap{padding:10px 12px;background:var(--surface);border:1px solid var(--border);border-radius:6px;display:flex;justify-content:space-between;cursor:pointer;font-size:14px}
.wifilist .ap:hover{background:var(--purple-soft);border-color:var(--purple)}
.wifilist .ap:active{background:var(--purple-soft)}
.toggle{display:flex;align-items:center;gap:12px;margin:8px 0;padding:10px 12px;background:var(--surface);border:1px solid var(--border);border-radius:8px}
.toggle input{width:20px;height:20px;flex:0 0 auto;accent-color:var(--orange)}
.toggle label{margin:0;color:var(--text);font-size:14px;flex:1;font-weight:500}
table{width:100%;border-collapse:collapse;font-size:14px;margin-top:6px}
td{padding:6px 6px;border-bottom:1px solid var(--border)}
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

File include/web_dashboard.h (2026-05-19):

#pragma once

#include <Arduino.h>

// Live snapshot of sensor readings + connectivity, fed into the dashboard's
// /api/status endpoint. main.cpp owns the source of truth and just calls
// updateStatus() periodically.
struct DashboardStatus {
  // Connectivity
  bool sta_connected = false;
  String sta_ip;
  String sta_ssid;
  int    sta_rssi = 0;
  bool   ws_connected = false;
  uint32_t last_post_ms = 0;     // millis() of last successful publish
  String last_publish_at;        // human-readable, optional

  // Latest readings (NAN/0 if unavailable)
  float temp_c = NAN;
  float humidity = NAN;
  float pressure_hpa = NAN;
  float lux = NAN;
  unsigned int rain_raw = 0;
  unsigned int pm1 = 0;
  unsigned int pm25 = 0;
  unsigned int pm10 = 0;
  bool   has_temp = false;
  bool   has_humidity = false;
  bool   has_pressure = false;
  bool   has_lux = false;
  bool   has_pm = false;

  // Nostr identity (display)
  String npub;       // bech32 "npub1..." computed in main.cpp
  String pubkey_hex;

  // Stable hardware identity (eFuse MAC suffix, matches AP SSID suffix)
  String device_id;
};

// Side effects triggered by the dashboard when the user changes config.
struct DashboardCallbacks {
  // Called after config has been persisted; main.cpp should re-apply any
  // subsystems that depend on the changed fields. Bitmask via the booleans.
  void (*onApply)(bool wifiChanged,
                  bool relayChanged,
                  bool keyChanged,
                  bool sensorsChanged,
                  bool intervalChanged) = nullptr;
  void (*onRestart)() = nullptr;
  void (*onFactoryReset)() = nullptr;
  void (*onRegenerateKey)() = nullptr;
};

namespace web_dashboard {
  // Start AP+STA, DNS captive portal, HTTP server, and mDNS. Safe to call
  // exactly once from setup().
  void begin(const DashboardCallbacks& cb);

  // Service HTTP + DNS requests. Call from loop() on every tick.
  void handle();

  // Push the latest sensor + connectivity snapshot. Cheap; copy by value.
  void updateStatus(const DashboardStatus& snapshot);

  // AP IP (typically 192.168.4.1). Useful for log messages.
  String apIp();
  String apSsid();
}

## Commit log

2025-12-09 better links to sample app
2025-12-11 switch to 9600 beaud rate (deafult) for pm25
2025-12-25 send staiton metadata event and small fixes
    [main.cpp]
2025-12-25 support more pm sensor readings
2025-12-25 air quality sensor
2025-12-25 update events to better support multiple sensor types
2025-12-25 weather station meta; power & connection mode
2025-12-26 wip - bulid for two diff board types
2025-12-26 fail fast on misconfigured sensors
    [main.cpp]
2025-12-26 doc in sample settings teh sensor options
2025-12-27 conditional readings based on enabled sensors
2026-01-04 fix/support bmp280 sensor
2026-05-04 Add SDS011 station 6 support (UART), SPS30 hooks for station 5, PlatformIO SDS lib from Git, I2C init when OLED-only.
2026-05-07 first draft of enclosure
2026-05-09 enclosure generation
2026-05-18 assembly guide
2026-05-18 mvp board config
2026-05-19 mvp board normalisation
2026-05-19 fix last published issue, theme the wires and optimise guide
    [main.cpp, web_dashboard.cpp]
2026-05-23 rain sensor value check for sensor status reporting
2026-05-23 rain sensor++
2026-05-24 mvp boards ++
2026-07-03 3d models for mvp stations
    [1_base_with_text.stl, 2a_tier_esp32.stl, 2b_tier_solid.stl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]
